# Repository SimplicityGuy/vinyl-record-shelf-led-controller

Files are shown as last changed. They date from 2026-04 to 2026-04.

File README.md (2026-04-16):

# WS2812B LED Controller — Vinyl Record Shelf Finder

PCB for the hardware layer of the vinyl record shelf finder: a system that illuminates the correct cube of a Kallax 4×4 shelf when you look up a vinyl record. The shelf-finder application lives in [vinyl-record-shelf-gopher](https://github.com/SimplicityGuy/vinyl-record-shelf-gopher) and uses record metadata from [discogsography](https://github.com/SimplicityGuy/discogsography).

PCB Rev 10

## Overview

A Raspberry Pi 4B queries a PostgreSQL database for a record's shelf location, then fires an HTTP call to WLED running on a Seeed XIAO ESP32C6. The ESP32C6 drives the correct WS2812B LED strip, lighting up the cube containing that record.

```mermaid
flowchart TD
    PI[Raspberry Pi 4B]
    ESP["XIAO ESP32C6<br/>(WLED)"]
    LS["74AHCT125<br/>3.3V → 5V level shift"]
    C1[Cube 1 LEDs]
    C2[Cube 2 LEDs]
    C16[Cube 16 LEDs]

    PI -->|WiFi HTTP| ESP
    ESP --> LS
    LS --> C1
    LS --> C2
    LS -.-> C16
```

## PCB Specifications

| Parameter | Value |
|---|---|
| Dimensions | 68 × 50 mm |
| Layers | 2 (F.Cu, B.Cu) |
| Min trace width | 0.25 mm (signal) / 1.0 mm (power) |
| PCB thickness | 1.6 mm |
| Surface finish | ENIG (OSH Park) |
| Assembly | All through-hole, hand solderable |
| Mounting | 4 × M3 corner holes, 10 mm standoffs |
| Connectors | Top edge: USB-C (XIAO), DC barrel jack, LED terminal block |

## Schematic

The signal path:

```mermaid
flowchart TD
    A["XIAO D1<br/>GPIO3 (3.3V)"]
    B[R1 470Ω series]
    C["U2 74AHCT125<br/>1A → 1Y<br/>3.3V → 5V shift"]
    D[J2 DATA pin]
    E[WS2812B Strip Din]

    A --> B --> C --> D --> E
```

Power:
- 5V in via J1 (CUI PJ-102AH barrel jack, center positive)
- 5V rail shared between LED strips (via J2) and XIAO VBUS
- 3.3V generated by XIAO's onboard regulator → decoupled by C4

## Bill of Materials

See [BOM.csv](docs/BOM.csv) for the full sourced BOM with DigiKey part numbers.

| Ref | Part | Description | Qty |
|---|---|---|---|
| U1 | XIAO-ESP32-C6 | Seeed XIAO ESP32C6 module | 1 |
| U2 | SN74AHCT125N | 74AHCT125 level shifter, DIP-14 | 1 |
| — | ED14DT | On Shore DIP-14 socket | 1 |
| C1 | UKL1C101KPDANA | Nichicon 100µF/16V electrolytic, P3.5mm | 1 |
| C2, C3, C4 | K104K15X7RF53H5G | Vishay KG 100nF X7R, 50V, P5.0mm | 3 |
| R1 | LR1F470R | TE 470Ω ¼W axial, P7.62mm | 1 |
| J1 | PJ-102AH | CUI DC barrel jack 2.1mm right-angle | 1 |
| J2 | 0397000803 | Molex 3-pos Eurostyle terminal block 5.00mm | 1 |
| MH1–4 | — | M3 × 6mm screws + 10mm brass standoffs | 4 |

## LED Strip Wiring

16 × WS2812B strips (one per Kallax cube). All strips share the 5V/GND power bus. Data is a single daisy-chain through all 16.

```
J2 +5V ──────────────────────── ●  ●  ●  ... ●   (all 16 strip +5V pads)
J2 GND ──────────────────────── ●  ●  ●  ... ●   (all 16 strip GND pads)
J2 DATA → Strip1 Din
           Strip1 Dout → Strip2 Din
                          Strip2 Dout → ... → Strip16 Din
```

Cube numbering (top-left = 1, bottom-right = 16, row-major):

```
┌────┬────┬────┬────┐
│  1 │  2 │  3 │  4 │  ← Row 1
├────┼────┼────┼────┤
│  5 │  6 │  7 │  8 │  ← Row 2
├────┼────┼────┼────┤
│  9 │ 10 │ 11 │ 12 │  ← Row 3
├────┼────┼────┼────┤
│ 13 │ 14 │ 15 │ 16 │  ← Row 4
└────┴────┴────┴────┘
```

## WLED Configuration

| Setting | Value |
|---|---|
| LED type | WS2812B |
| Data pin | GPIO3 (D1) |
| Total LEDs | 16 × (LEDs per strip) |
| Segments | 16 (one per cube, equal length) |
| Color order | GRB |
| Voltage | 5V |

Each cube maps to one WLED segment. The [vinyl-record-shelf-gopher](https://github.com/SimplicityGuy/vinyl-record-shelf-gopher) service sends an HTTP request to activate the segment corresponding to the record's cube location. API specification: TBD.

## J1 Barrel Jack Pinout

| Pin | Function | Note |
|---|---|---|
| 1 (sleeve, square pad) | GND | |
| 2 (tip) | +5V | Center positive |
| 3 (switch, side) | GND | Tied to GND on PCB |

⚠️ **Center positive only.** Verify polarity with a multimeter before first power-up.

## J2 Terminal Block Pinout

| Pin | Signal | Wire color |
|---|---|---|
| 1 (square pad) | +5V | Red |
| 2 | GND | Black |
| 3 | DATA (5V logic) | Yellow |

## Assembly

See [ASSEMBLY.md](docs/ASSEMBLY.md) for the full step-by-step guide covering PCB population, LED strip installation, wiring, and system test.

**Soldering order (shortest to tallest):**
1. R1 (470Ω axial)
2. C2, C3, C4 (100nF ceramic disc)
3. C1 (100µF electrolytic — observe polarity)
4. ED14DT DIP socket (not the IC)
5. J1 barrel jack
6. J2 terminal block
7. XIAO female socket headers (1×7 × 2)
8. SN74AHCT125N into socket (after power test)
9. XIAO ESP32C6 module

## Fabrication

Designed for [OSH Park](https://oshpark.com) 2-layer service. Upload `controller/ws2812b_controller.kicad_pcb` directly.

To generate gerbers in KiCAD 7:
1. Open `controller/ws2812b_controller.kicad_pcb`
2. File → Fabrication Outputs → Gerbers
3. Output to `controller/gerbers/`
4. Also generate drill files from the same dialog

## Software

WLED firmware is flashed to the XIAO ESP32C6 before installation. The shelf-finder application lives in [vinyl-record-shelf-gopher](https://github.com/SimplicityGuy/vinyl-record-shelf-gopher), which consumes record metadata from [discogsography](https://github.com/SimplicityGuy/discogsography) and issues the WLED segment calls to this controller. API specification: TBD.

## License

Hardware designs released under [CERN OHL-P v2](LICENSE).

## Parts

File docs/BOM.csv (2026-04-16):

Reference | Quantity | Value | Footprint | Part Number | Manufacturer | DigiKey PN | Description | Unit Price USD | Notes
U1 | 1 | XIAO ESP32C6 | Seeed Studio XIAO Series Library:XIAO-ESP32-C6-DIP | XIAO-ESP32-C6 | Seeed Studio |  | WiFi6+BLE5 module on 2×7 pin DIP socket | 6.20 | Flash WLED before installing
U2 | 1 | SN74AHCT125N | Package_DIP:DIP-14_W7.62mm | SN74AHCT125N | Texas Instruments | 296-4655-5-ND | Quad buffer 3-state 3.3V→5V level shifter DIP-14 | 0.80 | Install after power test
 | 1 | ED14DT | Package_DIP:DIP-14_W7.62mm | ED14DT | On Shore Technology | ED3045-5-ND | DIP-14 tin socket for SN74AHCT125N | 0.17 | Solder socket first not IC
C1 | 1 | 100µF 16V | Capacitor_THT:CP_Radial_D8.0mm_P3.50mm | UKL1C101KPDANA | Nichicon | 493-13396-ND | Aluminum electrolytic 100µF 10% 16V radial φ8mm P3.5mm | 0.58 | POLARIZED — long lead (+) to square pad
C2 | 1 | 100nF 50V | Capacitor_THT:C_Disc_D3.4mm_W2.1mm_P5.00mm | K104K15X7RF53H5G | Vishay Beyschlag | 56-K104K15X7RF53H5G-ND | 100nF X7R 10% 50V radial ceramic disc H5 style P5.0mm | 0.48 | Not polarized
C3 | 1 | 100nF 50V | Capacitor_THT:C_Disc_D3.4mm_W2.1mm_P5.00mm | K104K15X7RF53H5G | Vishay Beyschlag | 56-K104K15X7RF53H5G-ND | 100nF X7R 10% 50V radial ceramic disc H5 style P5.0mm | 0.48 | Not polarized
C4 | 1 | 100nF 50V | Capacitor_THT:C_Disc_D3.4mm_W2.1mm_P5.00mm | K104K15X7RF53H5G | Vishay Beyschlag | 56-K104K15X7RF53H5G-ND | 100nF X7R 10% 50V radial ceramic disc H5 style P5.0mm | 0.48 | Not polarized
R1 | 1 | 470Ω | Resistor_THT:R_Axial_DIN0207_L6.3mm_D2.5mm_P7.62mm | LR1F470R | TE Connectivity | A105960CT-ND | 470Ω 1% 0.6W metal film axial P7.62mm | 0.03 | Data line series resistor
J1 | 1 | PJ-102AH | Connector_BarrelJack:BarrelJack_CUI_PJ-102AH_Horizontal | PJ-102AH | Same Sky (CUI) | CP-102AH-ND | DC barrel jack 2.1mm center-positive right-angle THT | 0.71 | CENTER POSITIVE — verify before power-up
J2 | 1 | 0397000803 | TerminalBlock_Phoenix:TerminalBlock_Phoenix_MKDS-1.5-3_1x03_P5.00mm_Horizontal | 0397000803 | Molex | WM22185-ND | 3-position Eurostyle push-in terminal block 5.00mm pitch | 2.23 | +5V / GND / DATA to LED strip
MH1 | 1 | M3 | MountingHole:MountingHole_3.2mm_M3 |  |  |  |  | M3 × 6mm screw + 10mm brass standoff | 0.10 | Corner mounting
MH2 | 1 | M3 | MountingHole:MountingHole_3.2mm_M3 |  |  |  |  | M3 × 6mm screw + 10mm brass standoff | 0.10 | Corner mounting
MH3 | 1 | M3 | MountingHole:MountingHole_3.2mm_M3 |  |  |  |  | M3 × 6mm screw + 10mm brass standoff | 0.10 | Corner mounting
MH4 | 1 | M3 | MountingHole:MountingHole_3.2mm_M3 |  |  |  |  | M3 × 6mm screw + 10mm brass standoff | 0.10 | Corner mounting

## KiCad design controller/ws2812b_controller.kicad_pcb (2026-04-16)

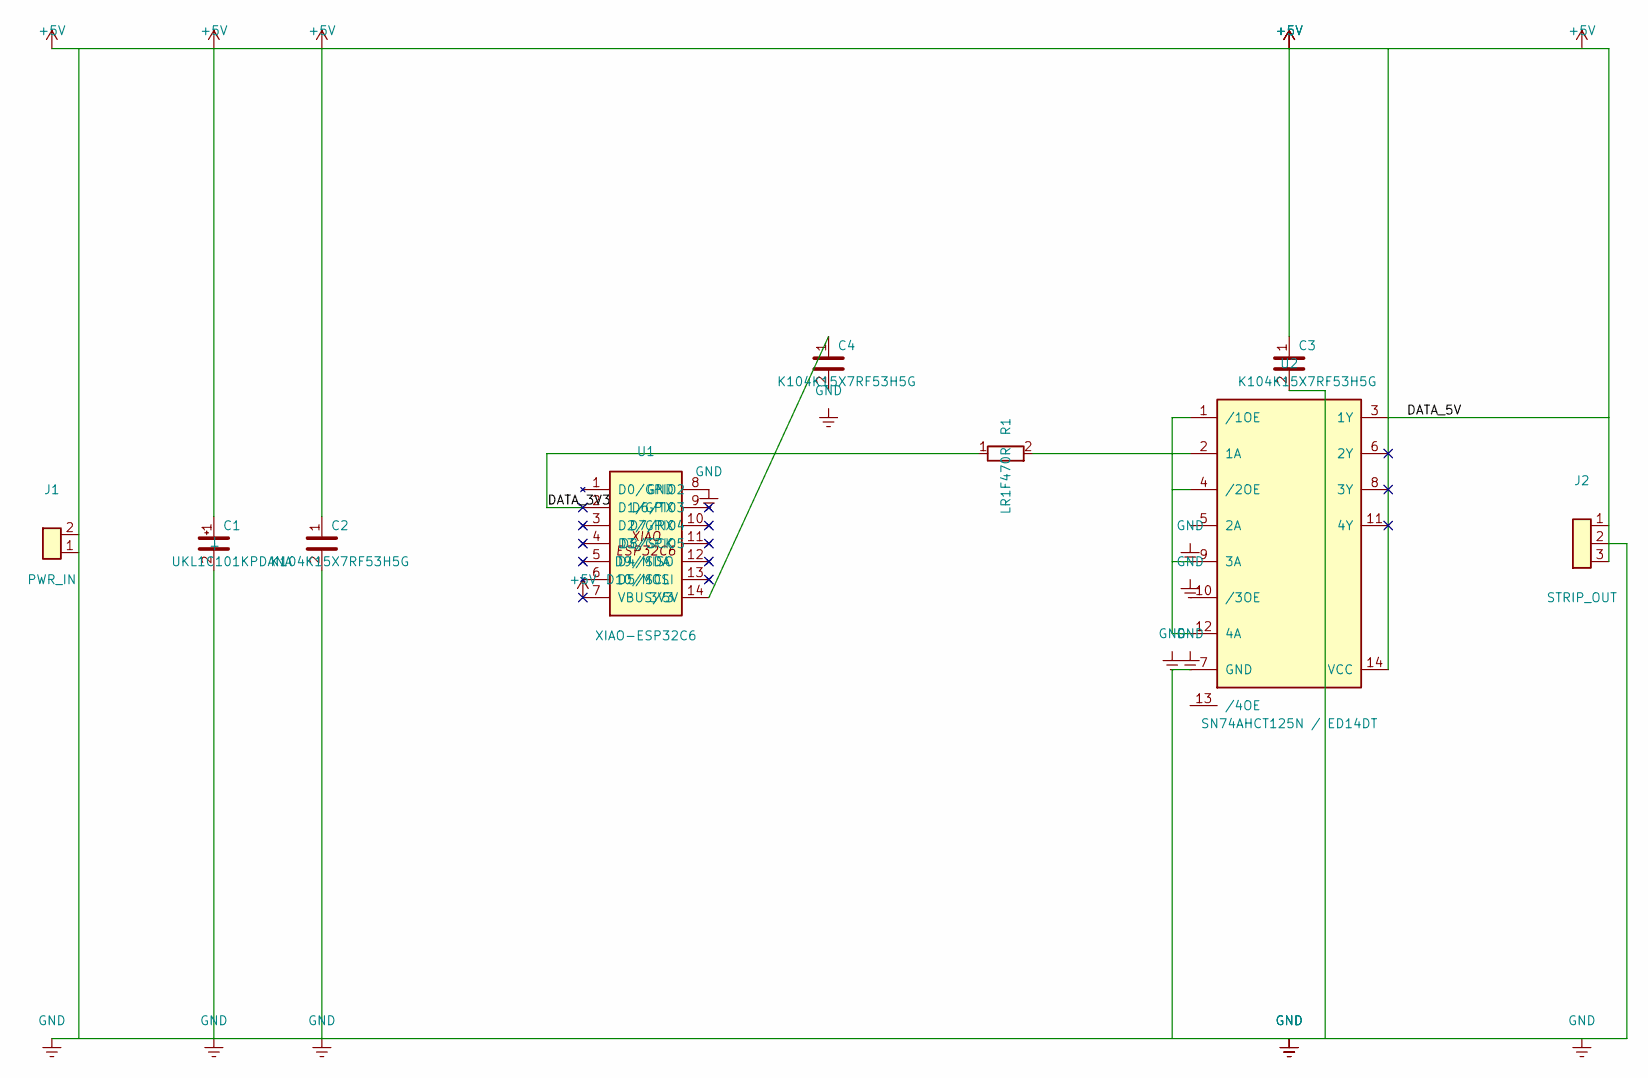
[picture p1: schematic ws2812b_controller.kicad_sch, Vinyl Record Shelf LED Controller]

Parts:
C1: UKL1C101KPDANA; CP_Radial_D8.0mm_P3.50mm
C2, C3, C4: K104K15X7RF53H5G; C_Disc_D3.4mm_W2.1mm_P5.00mm
J1: PWR_IN; BarrelJack_CUI_PJ-102AH_Horizontal
J2: STRIP_OUT; TerminalBlock_Phoenix_MKDS-1,5-3_1x03_P5.00mm_Horizontal
R1: LR1F470R; R_Axial_DIN0207_L6.3mm_D2.5mm_P7.62mm
U1: XIAO-ESP32C6; XIAO-ESP32-C6-DIP
U2: SN74AHCT125N / ED14DT; DIP-14_W7.62mm

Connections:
+5V: C1.1 (+), C2.1, C3.1, J2.3, U1.7 (VBUS/5V)
/DATA_3V3: R1.1, U1.2 (D1/GPIO3)
/DATA_5V: U2.3 (1Y)
GND: C1.2 (-), C2.2, J2.2, U1.8 (GND)
unnamed: C4.1, U1.14 (3V3)
unnamed: R1.2, U2.2 (1A)
unnamed: U2.1 (/1OE), U2.12 (4A)

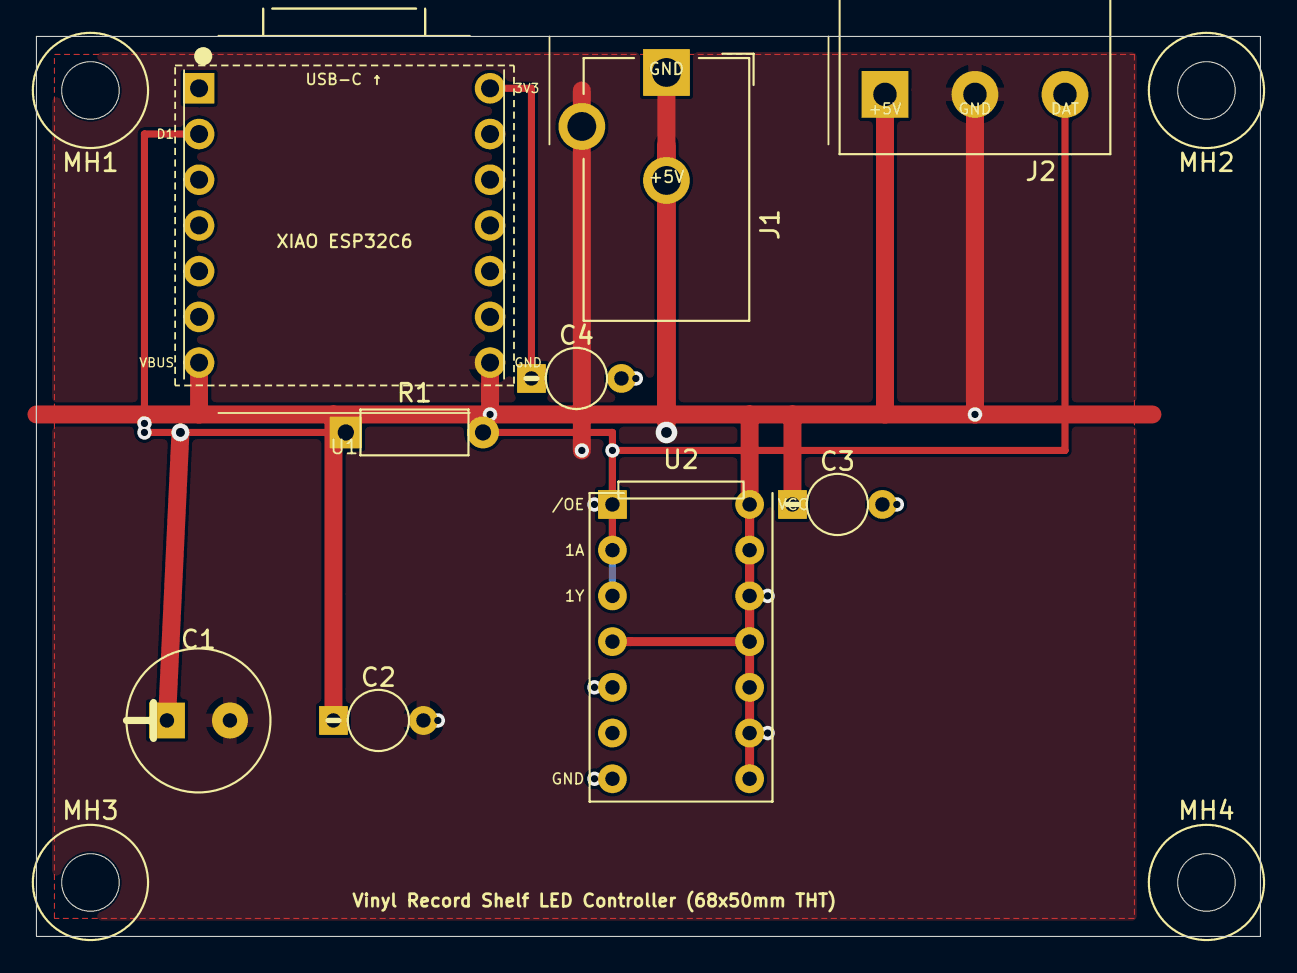
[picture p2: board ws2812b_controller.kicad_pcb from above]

Board: 2 copper layers, 68.0 x 50.0 mm, 13 parts (0 on the bottom side), 6 nets.

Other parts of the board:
MH1, MH2, MH3, MH4: M3; MountingHole_3.2mm_M3

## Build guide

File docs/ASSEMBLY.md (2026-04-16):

# Assembly Instructions

WS2812B LED Controller — Vinyl Record Shelf Finder  
PCB rev 1 · 68 × 50 mm · All through-hole

---

## Tools Required

- Temperature-controlled soldering iron (set to 320–350°C)
- 63/37 or no-clean solder
- Flux pen
- Solder wick / desoldering pump
- Multimeter
- Wire strippers, side cutters
- Flat-head screwdriver (for J2 terminal block)
- M3 screwdriver
- Isopropyl alcohol + brush (flux cleanup)
- PCB holder / helping hands

---

## Part 1 — PCB Assembly

Solder in order of component height, shortest first.

### Step 1 — PCB Preparation

1. Inspect all holes — confirm they are clear.
2. Install four M3 brass standoffs up through the bottom of MH1–MH4 and finger-tighten from above. This is much easier before the board is populated.
3. All components mount on the **top face (F.Cu)**.

### Step 2 — R1: 470Ω Axial Resistor (LR1F470R)

1. Bend leads to 7.62mm pitch.
2. Insert into R1 — not polarized, either orientation.
3. Tape or bend leads to hold flat, solder from the bottom, clip leads.

### Step 3 — C2, C3, C4: 100nF Ceramic Disc (K104K15X7RF53H5G)

These use H5-style flat-crimp leads at exactly **5.0mm pitch** — do not bend them.

1. Insert each cap — not polarized.
2. Solder from the bottom, clip.
3. Verify C4 (between J1 and the XIAO area) has visible clearance from J1 before soldering.

### Step 4 — C1: 100µF Electrolytic (UKL1C101KPDANA)

> ⚠️ **Polarized.** Installing backwards will cause failure on power-up.

1. The **longer lead is positive (+)**.
2. The **white stripe on the sleeve marks the negative side**.
3. Insert with the positive (long) lead into the **square pad** (marked `+` on silkscreen).
4. Solder and clip.

### Step 5 — ED14DT DIP Socket (for U2)

> ℹ️ Solder the **socket**, not the IC. The IC goes in after the power test.

1. Insert the ED14DT socket into U2 footprint.
2. The **notch** on the socket = pin 1. Align with the **square pad** (top-left of U2 outline on silkscreen).
3. Tack two diagonal corners, verify alignment, solder all 14 pins.

### Step 6 — J1: Barrel Jack (PJ-102AH)

1. Insert J1 so the barrel protrudes above the top board edge.
2. Pin 3 (switch) sits on the **left** side of the connector (away from J2).
3. Solder all three pins. The sleeve/GND pad (pin 1, square) carries all return current — use a generous solder fillet.

### Step 7 — J2: Terminal Block (Molex 0397000803)

1. Insert J2 so the push-button wire openings face **up and outward** beyond the top board edge.
2. Pin 1 (square pad) is on the **left** — labeled `+5V` on silkscreen.
3. Pin order left to right: `+5V` · `GND` · `DAT`.
4. Solder all three pins.

### Step 8 — XIAO Socket Headers

The XIAO ESP32C6 module plugs into two 1×7 female socket headers. The module is **not** soldered.

1. Insert both headers into U1L (left) and U1R (right). Pin 1 of each (square pad) is at the top.
2. **Use the XIAO module as an alignment jig** — press it gently into both headers before soldering to guarantee perfect spacing.
3. Solder one pin of each header, verify alignment, then solder the rest.
4. Remove the XIAO module.

### Step 9 — Flash WLED, Then Install XIAO

1. Flash WLED firmware onto the XIAO while it is loose (easier than in-board).
2. Complete initial WLED Wi-Fi setup.
3. Orient the XIAO with USB-C toward the top board edge (`USB-C ↑` silkscreen label).
4. Press firmly and evenly into both socket headers until fully seated.

### Step 10 — Pre-Power Checks

1. Visual inspection — look for solder bridges especially on the ED14DT socket.
2. With **no power applied**, measure resistance between `+5V` and `GND` on J2. Should be > 1kΩ. Near-zero = bridge.

### Step 11 — First Power-Up

> ⚠️ Verify the supply is **center-positive** before plugging into J1.

1. Plug in the 5V supply.
2. Measure `+5V` vs `GND` at J2 → should read 4.9–5.1V.
3. Measure `3V3` vs `GND` at U1R pin 1 → should read 3.2–3.4V.
4. If either reading is wrong, disconnect and diagnose before continuing.

### Step 12 — Install SN74AHCT125N

1. Only after voltages check out.
2. Align the **notch on the IC** with the **notch on the ED14DT socket** (both point toward the top edge).
3. Press firmly and evenly across the full width — confirm all 14 pins seat correctly.

---

## Part 2 — Shelf Installation

### Step 13 — Cut and Label LED Strips

Cut 16 strips, one per Kallax cube, approximately 300mm each. Cut only at the copper pad marks between LED packages.

Label strips 1–16 before installation:

```
Row 1 (top):    1   2   3   4
Row 2:          5   6   7   8
Row 3:          9  10  11  12
Row 4 (bottom):13  14  15  16
```

Pre-tin the three solder pads on each cut end.

### Step 14 — Mount Strips in Cubes

1. Wipe the back wall of each cube with isopropyl alcohol and allow to dry.
2. Adhere the strip horizontally along the back wall, LEDs facing outward.
3. Supplement adhesive with hot glue at each end if needed (Kallax surfaces can be waxy).
4. Feed wires out through the back of the shelf. Drill a 6mm hole in the back panel corner if needed.

### Step 15 — Wire the Power Bus

Run a **red wire** (+5V) and **black wire** (GND) from J2 to every strip in **parallel**. Solder at each strip pad. Cable-tie the bus every 150mm.

### Step 16 — Daisy-Chain the Data Line

Run **yellow wire** from J2 pin 3 (DATA) to strip 1's `Din` pad. Then:

```
J2 DATA → Strip 1 Din
           Strip 1 Dout → Strip 2 Din
                           Strip 2 Dout → ... → Strip 16 Din
```

The arrow on the WS2812B strip indicates the data direction — always `Dout → Din`.

> ⚠️ Follow the cube numbering order (1→16) precisely. WLED segment mapping relies on physical chain order.

Insulate all exposed solder joints with heat-shrink tubing.

### Step 17 — Mount PCB

1. Hold the PCB in the intended position on the back of the shelf (above cube row 1, accessible from the top).
2. Mark four M3 hole positions using the PCB as a template.
3. Drill 3.5mm holes through the Kallax back panel.
4. Fasten PCB with M3 × 6mm screws through the board into the standoffs.

### Step 18 — Final Connections

1. **J2** — Insert the three bus wires. Press the orange push-button above each terminal to open, insert stripped wire (9–10mm), release. Pull gently to confirm grip.
2. **J1** — Plug in the 5V supply barrel. Confirm center-positive.
3. **Raspberry Pi** — joins over Wi-Fi; no physical PCB connection needed.

### Step 19 — System Test

1. Apply power. WLED should boot and appear on Wi-Fi.
2. In WLED, set LED count to total LEDs across all strips. Set solid white — verify all 16 cubes light.
3. Create 16 equal segments. Activate each in turn and confirm correct cube illuminates (cube 1 = top-left, cube 16 = bottom-right).
4. Measure supply current at full white brightness. Confirm it is within your PSU rating.
5. Record each record's cube assignment in [vinyl-record-shelf-gopher](https://github.com/SimplicityGuy/vinyl-record-shelf-gopher). Schema: TBD.

---

## Connector Quick Reference

**J1 — DC Power In (PJ-102AH)**

| Pin | Signal |
|---|---|
| 1 — sleeve (square pad) | GND |
| 2 — tip | +5V (center positive) |
| 3 — switch (side) | GND (tied on PCB) |

**J2 — LED Strip Out (Molex 0397000803)**

| Pin | Signal | Wire |
|---|---|---|
| 1 — square pad | +5V | Red |
| 2 | GND | Black |
| 3 | DATA (5V) | Yellow |

**U1 — XIAO Socket (key pins)**

| Position | Signal |
|---|---|
| U1L pin 2 | D1 / GPIO3 → DATA_3V3 |
| U1L pin 7 | VBUS / +5V |
| U1R pin 1 | 3V3 |
| U1R pin 7 | GND |

---

## Estimated Build Times

| Phase | Time |
|---|---|
| PCB population (all through-hole) | 45–60 min |
| LED strip cutting and pre-tinning | 30 min |
| Cube installation (16 cubes) | 45–60 min |
| Wiring (power bus + data chain) | 30–45 min |
| PCB mounting and final connections | 15 min |
| System test | 15 min |
| **Total** | **~3.5 hours** |

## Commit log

2026-04-16 feat(hardware): add WS2812B LED controller PCB
    68×50mm 2-layer PCB for the Kallax 4×4 vinyl record shelf finder
    hardware layer of discogsography. Drives 16 WS2812B LED strips (one
    per cube) via WLED on a Seeed XIAO ESP32C6, commanded by a Raspberry
    Pi 4B over WiFi HTTP.
    Components:
    - Seeed XIAO ESP32C6 (female socket headers, not soldered)
    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
    [BOM.csv, ws2812b_controller.kicad_pcb, ws2812b_controller.kicad_sch]
2026-04-16 chore: cleanup
    [BOM.csv]
